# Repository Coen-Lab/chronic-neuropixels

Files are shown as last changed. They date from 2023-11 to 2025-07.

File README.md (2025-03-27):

# Apollo Implant Parts List and Instructions
For more information on the chronic implant detailed in this repository, please refer to our [eLife paper](https://elifesciences.org/articles/98522).  

## Issues and Discussions
* NOTE: On 14/06/2024 the files were updated to allow for larger inter-probe distances (a commonly requested feature). We believe this works well, but we have not tested the updated parts ourselves. Please contact us if you have any issues. This will change the behaviour of the parts slightly for Inter-Probe distances between 2 & 4 mm (in short, the height of the payload walls now increases, rather than the lid being extended). If you want to continue using the older files, please use an earlier version of the repository.
* If you have any problems with the implant, or difficulty sourcing the components etc. please use the "Issues" feature of github. 
* If you have ideas/feature requests or you want to ask a question, please use the "Discussions" feature of github. 
* If you have designed your own adaptations to the Apollo Implant that you think would be useful to the community, please submit a pull request to the repository, following the instructions shown [here](https://github.com/Coen-Lab/chronic-neuropixels/tree/main/XtraModifications).

## NOTE
Please be aware that all .ipt files were created useing Autodesk Inventor _2023_. To edit the files and save them in your preferred format, you will need to download this software [free for educational use](https://www.autodesk.com/education/edu-software/overview?sorting=featured&filters=individual). You will need the _2023_ version, or later, to open/edit the files.
 <br>
 <br>

The [commercially available NP2.0](https://www.neuropixels.org/order) probes have a different form-factor from the previous release (NP2_Alpha). We have an implant for the new version, and the design is posted here. However, it has undergone less testing, so please let us know if you have any issues with these parts, or if you use them successfully! Most of the images below reference the NP2_Alpha build, although the same documentation applies to both versions and we plan to update this in the future. There are two versions of the commercially available NP2.0 probes: those with a "metal cap" (also called a dovetail) and those without. The Apollo Implant will be tested with probes that do _not_ have the metal cap, to minimise the size and weight of chronic implants. However, with the adjustable parameters, it should be possible to accomodate probes with metal caps as well.

## Parts List
In this repository are all the parts required to build the chronic implant (not including glue, dental cement, etc.).
Files are adjustable using annotated parameter tables. Please watch “SupplementaryVideo_1.mp4” ([found here](https://www.biorxiv.org/content/10.1101/2023.08.03.551752v3.supplementary-material)) if you are unfamiliar with this process. You will also need Autodesk Inventor which is free for educational use. This allows you to, for example, change the angle of the docking module, spacing between probes, or thickness of the walls. However, be aware that parameters like “length of exposed probes” are estimates based on our own use and not exact. The default values are those we use in the lab for a typical insertion, although we change them as needed. 

Files are also inter-linked, such that changes you make to the parameters of Payload will cause changes in Docking, and DockingHolder. Usually, these are changes you want because it means all the parts will fit together. However, you should be aware that these are happening, and can be overridden if needed.

Files specific to versions 1 and 2 of Neuropixels are in NP1 and NP2 folders. Other parts are in the base folder and can be used (in some cases with a parameter change) for either version. NOTE: The "PayloadHolder" was updated on 27/09/2023 to add a minor adjustment for NP1 sizing. The "PayloadCap" was updated on 13/10/2023 for a minor adustment to better-accommodate NP1 probe thickness.

- [Payload module](https://github.com/Coen-Lab/chronic-neuropixels/tree/main#np1_payload-or-np2-alpha_payload)
- [Payload module holder](https://github.com/Coen-Lab/chronic-neuropixels/tree/main#np1_payloadholder-or-np2-alpha_payloadholder)
- [Lid](https://github.com/Coen-Lab/chronic-neuropixels/tree/main#np1_payloadlid-or-np2-alpha_payloadlid)
- [Docking module](https://github.com/Coen-Lab/chronic-neuropixels/tree/main#np1_docking-or-np2-alpha_docking)
- [Docking module holder](https://github.com/Coen-Lab/chronic-neuropixels/tree/main#np1_dockingholder-or-np2-alpha_dockingholder)
- [Constructor head](https://github.com/Coen-Lab/chronic-neuropixels/tree/main#universal_constructorhead)
- [Universal probe sharpener](https://github.com/Coen-Lab/chronic-neuropixels/tree/main#universal_probesharpener)

&nbsp;
### “NP1_Payload” or “NP2-Alpha_Payload”
This is the module that holds the probe(s). You will need one of these for each probe (or pair of probes) you use, and it is re-used across implantations. Print in Natural Rigid Resin 4000, including 4x M1 threaded inserts.

<p align="center">


</p>

&nbsp;
### “NP1_PayloadHolder” or “NP2-Alpha_PayloadHolder”
This is a holder that can be attached to the Payload Module for construction, painting, implants, storage, carrying around etc. There are two versions which can be produced from the save file by adjusting the binary “REDUCEDHOLDERVERSION” parameter.
*If REDUCEDHOLDERVERSION is "0", you will see the version used for payload construction (below, left). You only need one of these. Print in PA12, including 2x M3 insert.
*If REDUCEDHOLDERVERSION is "1", you will see the reduced version used general manipulation, storage, insertion etc. You need as many of these as would be useful. Print in PA12, including 2x M3 insert.

<p align="center">


</p>

&nbsp;
### “NP1_PayloadLid” or “NP2-Alpha_PayloadLid”
This is the lid for Payload Module, to be attached with glue after the probe is cemented in position. You will need one per probe. Print in PA12.  

<p align="center">


</p>

&nbsp;
### “NP1_Docking” or “NP2-Alpha_Docking”
This is the module that is cemented to the skull after being screwed to the Payload Module. A new Docking Module is required for each insertion. Print in Natural Rigid Resin 4000.  

<p align="center">


</p>

&nbsp;
### “NP1_DockingHolder” or “NP2-Alpha_DockingHolder”
This holds the Docking Module in place when using the constructor to combine the two modules. You only need one of these. Print in Natural Rigid Resin 4000, including 4x M3 insert.  
    
<p align="center">


</p>

&nbsp;
### “Universal_ConstructorHead”
This forms one end of the constructor setup (used to “safely” combine the docking and payload modules). You will only need one of these. Print in Natural Rigid Resin 4000.  
<p align="center">

</p>

&nbsp;
### “Universal_ProbeSharpener” 
This is a simple part that we use to hold the probe itself in order to sharpen them prior to construction. Note that it uses a screw to hold the probe: do not tighten it too much, or the probe base will break. 

&nbsp;
### Additional screws and bolts:
NOTE: Links are for reference but could be sourced elsewhere. The brass inserts can be easily inserted using a soldering iron and mild pressure. We typically do this in-house, but your 3D-printing company may also do this for you upon request.
* [M1 Brass knurled inserts](https://www.ebay.co.uk/itm/124738465135): To be heat-inserted into the Payload. Also available in large quantities on aliexpress from [many vendors](https://www.aliexpress.com/w/wholesale-m1-brass-inserts.html?spm=a2g0o.productlist.search.0).
* [M3 Brass knurled inserts](https://uk.rs-online.com/web/p/threaded-inserts/2040620): To be heat-inserted into the PayloadHolder and DockingHolder.
* [M1 Screws](https://www.accu.co.uk/cheese-head-screws/6425-SFE-M1-2-A2): To lock modules together (4 per module).
* [M3 5mm screws](https://www.accu.co.uk/flanged-button-screws/8592-SSBF-M3-5-A2): For connecting Payload Module holder to Thor Labs posts (3 total)
* [M3 10mm screws](https://www.accu.co.uk/flanged-button-screws/8595-SSBF-M3-10-A2): For connecting Constructor Head to Thor Labs posts (3 total) and also for securing the Docking Module in its holder (2-4 depending on your preference)
* [M3 20mm screws](https://www.accu.co.uk/flanged-button-screws/8600-SSBF-M3-20-A2): For tightening the payload module holder (one per payload module holder)
* [Thor labs posts](https://www.thorlabs.com/thorproduct.cfm?partnumber=MS3R/M): At least 3 for the constructor, more to hold the probes etc.

&nbsp;
&nbsp;
## Assembly 
NOTE: Links are for reference but could be sourced elsewhere. The brass inserts can be easily inserted using a soldering iron and mild pressure. We typically do this in-house, but your 3D-printing company may also do this for you upon request. 
This section describes how to put all the parts together. We recommend practicing on dummy probes (or even on probes that are already broken!) to get used to it, since specific steps can be finicky.   
### MATERIAL: 
* Blu Tack 
* Epoxy glue (e.g., Araldite ARA-400007) 
* Super glue 
* Silver wire and soldering  

&nbsp;
### 1. CHECKING THE PARTS: 
1.  Before fixing the probe, perform full assembly procedure without the probe to ensure the parts fit together. 

&nbsp;
### 2. FIXING A PROBE TO THE PAYLOAD MODULE 
1.  Using Blu Tack, position payload module and coat it with a thin layer of epoxy (so that the probe will stick to it). 
2.  Carefully bring the probe (usually holding the flex with two fingers and pushing the probe down with the index finger) onto the payload module. Make sure you push it to the end of the payload module. If you are aiming for a deeper implant than the parameters allow (>6.5 mm) you could push the probe beyond the end of the payload module. Check for probe alignment, and readjust the angle manually. Add more epoxy to fix the probe to the module – you can cover the base and parts of the electronics, but it’s usually good to avoid covering the GND and REF electrodes since they can be used to check for good soldering (or to solder GND and REF here directly). While applying epoxy, you can keep the probe in position using the tip of forceps. 
3.  Short the GND and the REF by soldering a silver wire in between (this can also be done beforehand). This step and the overall grounding are currently being discussed and improved (see troubleshooting). 
4.  Fold the flex and insert it in the slot on the inside of the lid. Then push the lid down and glue it by putting super glue on both sides of contact with the payload module. If you’ve soldered a silver wire for your ground, make sure it sticks out. You can then fold the flex and slide the connectors end in the slot on the outside of the lid. 
5.  You can now use the payload holder to sharpen your probe. 

<p align="center">

<p align="center">
Stage 2.3 (left) and 2.4 (right) 
</p>  
 
&nbsp;
### 3. FIXING A SECOND PROBE TO THE PAYLOAD MODULE 
These steps are only if you want a second probe. If you don’t, you can close the empty side with a lid and make sure you close all gaps with epoxy or kwikcast. If you do, please follow these steps:
1. You must first sharpen the second probe. To do so, you can use the temporary probe holder (we have been using “ProbeSharpener.stl” to hold the probe during this process, but this hasn’t been heavily optimized). 
2. Then, you can assemble the second probe by repeating the same steps as before, while being extra careful not to touch the probe that is already attached to the docking module.  
 
&nbsp;
### 4. ASSEMBLING THE PAYLOAD AND THE DOCKING MODULES 
1. Position the docking module in the docking module holder. 
2. Position the payload module (with the probes) in the payload module holder. This step is easier if the payload module holder is at that stage independent of the docking module holder. The probe is secured in the holder, and then the holder is screwed in. Check the alignment of the probe.  
3. Slide the docking module holder until the docking module is fully covering the payload module and that the holes are aligned to the threads. While sliding, check for the good alignment of the probe. Screw in (we found using forceps to hold the screws was easier).  
4.	Unscrew the docking module from the docking module holder. You can now slide it away from the probe.   
5.	Unscrew the now fully assembled implant from the payload module holder.   
 
<p align="center">

<p align="center">
Stage 4.2 (left) and 4.5 (right)  
</p>  

&nbsp;
&nbsp;

This work is licensed under a
[Creative Commons Attribution-NonCommercial-ShareAlike 4.0 International License][cc-by-nc-sa].

[][cc-by-nc-sa]

[cc-by-nc-sa]: http://creativecommons.org/licenses/by-nc-sa/4.0/
[cc-by-nc-sa-image]: https://licensebuttons.net/l/by-nc-sa/4.0/88x31.png
[cc-by-nc-sa-shield]: https://img.shields.io/badge/License-CC%20BY--NC--SA%204.0-lightgrey.svg

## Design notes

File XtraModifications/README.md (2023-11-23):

# Community-driven additional parts
<p align="justify"> In this folder, you will find parts generated by members of the Neuropixels community. The folder indicates the primary use of the part. Some of these will not be published, and may no longer be in active use. Please contact the designer listed if you have any questions. </p>

## Have a part to upload?
If you have a part to upload, please _submit a pull request_. In the interests of the community, please include the following in your commit: 
1. <p align="justify"> Add files to the folder that matches your use-case: Animal_State (e.g. Mouse_Headfixed or Rat_FreelyMoving). If the folder doesn't exist, you can create it (e.g. Platypus_FreelySwimming... I can hope). </p>
2. <p align="justify"> Add _one_ file per part and name the file according to ProbeType_Function (e.g. NP1_HeadstageHolder). </p>
3. <p align="justify"> Add parts in an editable format where possible _IF_ the software used is freely accessable to those in educational institutions. This will allow other members of the community to adjust the parts to their needs. Otherwise, upload a standard CAD format (e.g. STP or STL). </p>
4. Edit the README to include:
   * Sub-heading with the same name as your file.
   * A description of the part and how you use it.
   * One or two (but no more) images of the part.
   * The material that you typically use to print the part.
   * Your contact details.

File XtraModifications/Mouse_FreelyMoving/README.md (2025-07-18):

# Parts principally used with freely-moving mice
Each part will have a file associated with it, and where possible, this will be in an editable format. It will also include the material typically used to print the part, and the contact details of the designer. Please acknowledge the designer appropriately if you use any of these parts.  

- [NP1_HeadstageHolder](https://github.com/Coen-Lab/chronic-neuropixels/tree/main/XtraModifications/Mouse_FreelyMoving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)
- [NP1_HeadstageHolder_top & NP2-Alpha_HeadstageHolder_top](https://github.com/Coen-Lab/chronic-neuropixels/tree/main/XtraModifications/Mouse_FreelyMoving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)
- [NP2_SingleProbeMiniatureDockingWithHeadstageHolder & NP2_SingleProbeMiniaturePayload](https://github.com/Coen-Lab/chronic-neuropixels/tree/main/XtraModifications/Mouse_FreelyMoving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)
- [NP1_Payload_SingleProbe_Hollow & NP1_HeadstageHolder_DockingMount](#NP1_Payload_SingleProbe_Hollow-&-NP1_HeadstageHolder_DockingMount)
- [NP2_SingleProbeDockingWithHeadstage_ANGLED](#NP2_SingleProbeDockingWithHeadstage_ANGLED)

## NP1_HeadstageHolder
### Function
The NP1_HeadstageHolder was designed to allow free-moving recordings with the [Neuropixels 1.0 version](https://github.com/Coen-Lab/chronic-neuropixels/tree/main/NP1) of the Apollo implant and probes. It prevents damage to the ZIF pads during recordings. In our first recordings with the NP1 implant, we folded the probe flex underneath the caps (within the implant) so that the ZIF connector of the probe permanently protruded from the top of the implant (Fig 1A). During recordings, the headstage was connected to the probe and sat unsupported above the implant/animal.
<br>
<br>
Whilst recordings were possible in this configuration, the force exerted by the animal movement on the ZIF connector introduced noise into the recordings. This force and tension on the ZIF connector later damaged the gold pads on the flex, result in frequent error #14, 'BIST_ERROR', for the Parallel Serial Bus probe tests, which indicates a poorly seated probe. 
<br>
<br>
The headstage can be attached to the NP1_HeadstageHolder with epoxy (permanent) or a wrap of parafilm (temporary). Prior to recordings, the arms of the NP1_HeadstageHolder are slid onto the ridges of the NP1_Payload (as with the NP1_PayloadHolder) (Fig 1B). The probe flex is lopped between the NP1_Payload and NP1_HeadstageHolder and attached to the ZIF connector at the base (Fig 1C). Importantly, for this to work the flex needs to be full length. 

<p align="center">
  
</p>

### Material
Selective laser sintering. Material: Nylon PA12. Printed by: www.sgd3d.co.uk. Weight (without the headstage) = 0.5 g 

### Contact
Design was by Nathanael O'Neill, a postdoc in the Lignani lab, UCL email: skgtnon@ucl.ac.uk 
Freely moving recordings using NP1_HeadstageHolder were performed by Nathanael O'Neill and James Street 
The dimensions of the headstage mount of the NP1_HeadstageHolder were from [Emily A. Aery Jones](https://github.com/emilyasterjones)'s excellent [protocol](https://github.com/emilyasterjones/chronic_NPX_mouse) 

### Sofware used
Autodesk, Fusion360 2.0.17721 x86_64

## NP1_HeadstageHolder_top & NP2-Alpha_HeadstageHolder_top
### Function
This part was designed to facilitate freely-moving recordings using a single Neuropixels 1.0/2.0-Alpha probe. Its design is based on the Payload Holder, which was modified to fit the headstage and enable its connections.

*Advantages*
- Stability of probe-headstage connection increases SNR
- Easier and quicker to perform a recording (as the recording cable connection is easier to perform in an awake animal than the flex cable / ZIF connection)

*Disadvantages*
- Increased implant weight and height as mouse carries the headstage permanently

*How to use*
1. Protect the headstage electronics by applying some epoxy resin on it. Be mindful of the flex cable / ZIF connector. Wait at least 30 min for it to dry before applying epoxy on the other side of the headstage.
2. After printing the holder, verify that the headstage fits tightly inside it: it shouldn't move inside the holder, but also shouldn't be so tight that a great amount of force is needed to slide it in place. If necessary, file the inside of the holder to make room for the headstage.
3. Verify that the holder can be properly attached to the payload module. It should 'stick' to the payload module solely by friction. If necessary, after implantation you may add tape, dental cement, or other material to guarantee it will be secure in place, however keep in mind that you will need to do the reverse process during the explantation surgery!
4. (during surgery, after cementing and grounding the probe) Remove the implant from the Payload Holder and connect the headstage to the probe and slide it into the Headstage Holder as you mount the holder in the implant. Pay attention to the orientation of both the headstage (recording cable connection must align with the hole on the top of the holder) and the Holder (it must align with the grooves of the payload module, where it will slide in place). Slide it as much down as possible. In the end, verify that the connections are well-done by recording from the probe.
5. Cover the hole for the recording cable using a small piece of tape that can be removed for recordings, and glued back at the end of them. This will prevent dirt (*eg* cage bedding) from entering into the component.
6. Think about housing! A taller homecage is preferable, as is placing the food pellets in the floor of the cage and using a longer sipper tube for the water. Don't place small igloos or 'tunnels' in the cage.

In our hands, lighter mice (close to 20g in BW) take around 1 week to recover from the implantation surgery, while heaver mice (around 30g) take only a couple of days. We have attached the headstage and holder to the implant at the end of the implantation surgery, however you may perform this step on a separate surgery.

<p align="center">
  
</p>

### Material
Stereolithography (SLA) printing in a Form 2. Material: Resin Rigid 4000. Printed in-house. Weight (without the headstage) = 1.4 g (NP1.0) or 1.1g (NP2.0-Alpha)

### Contact
Design by Filipe Mendes (Champalimaud Research Hardware and Software Platform), Joana Catarino and José Teixeira (Systems Neuroscience / Mainen Lab). Freely-moving recordings using this component were performed by Joana Catarino and José Teixeira.
<br>

Filipe Mendes - filipe.mendes@research.fchampalimaud.org
<br>
Joana Catarino - joana.catarino@ki.se
<br>
José Teixeira - jose.gomesteixeira@donders.ru.nl

### Sofware used
Solidworks Professional SP5 2022

## NP2_SingleProbeDockingWithHeadstage_FullyParameterised & NP2_SingleProbeMiniaturePayload

### Function

This part was designed to have a minimal footprint, for a single Neuropixels 2.0 probe with a headstage that can be 
attached on the implant for long periods of time (e.g. in free moving experiments or in the homecage between 
experiments). The available .stp docking part leaves 3.5mm of probe exposed and has a contact angle of 16 degrees. A 
fully parameterised version is also included, which allows the user to set angles, tapers and amount of probe exposed.
This parameterised file was generated with Autodesk 2024 and is not backwards compatible.

Asset 4



## NP2-Alpha_SingleProbeDockingWithHeadstage & NP2-Alpha_SingleProbePayload

### Function

This part was designed to have a minimal footprint, for a single Neuropixels 2 Alpha probe with a headstage that can be 
attached on the implant for long periods of time (e.g. in free moving experiments or in the homecage between 
experiments). The available .stp docking part leaves 3.5mm of probe exposed and has a contact angle of 16 degrees.




### Material
Printed at SWC-FabLab with a Form 3. Material: Resin Rigid 4000.

### Contact
Design was by Simon Townsend (SWC FabLab, Sainsbury Wellcome Centre, UCL) with Stephen Lenzi (Margrie Lab).
<br>
Stephen Lenzi - s.lenzi@ucl.ac.uk
<br>
Simon Townsend - simon.townsend@ucl.ac.uk

### Sofware used
Autodesk Inventor 2023

##  NP1_Payload_SingleProbe_Hollow & NP1_HeadstageHolder_DockingMount ##

### Function

This design has a modified payload module for a single Neuropixels 1.0 probe achieving reduction in weight, and a headstage-holder that can be mounted to sides of any default NP1 docking module, achieving reduction in height. The trough-holes on the NP1 headstage are used to attach the headstage to the headstage holder (the holes on the holder require same threaded insert nuts as in the payoad module).

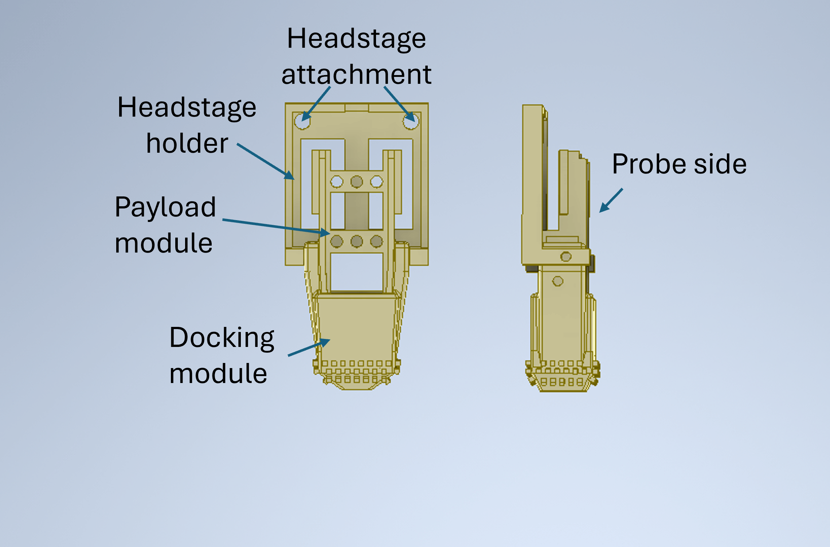
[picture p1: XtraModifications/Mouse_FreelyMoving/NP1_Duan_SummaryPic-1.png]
Asset 5


### Material
Printed at SWC-FabLab with a Form 3. Material: Resin Rigid 4000.

### Contact
Design by Ivana Orsolic (Duan Lab, Sainsbury Wellcome Centre, UCL) and Simon Townsend (SWC FabLab, Sainsbury Wellcome Centre, UCL).
<br>
Ivana Orsolic - i.orsolic@ucl.ac.uk
<br>
Simon Townsend - simon.townsend@ucl.ac.uk

### Sofware used
Autodesk Inventor 2023 & 2024

## NP2_SingleProbeDockingWithHeadstage_FullyParameterised_Fin & NP2_Mounting_bigger

### Function

This part is a modified version of the `NP2_SingleProbeDockingWithHeadstage_FullyParameterised`. It includes an added fin to improve stability and facilitate the assembly of the docking and payload components for Neuropixels 2 probes.
We have included files for a larger constructor specifically designed for Neuropixels 2.0 probes (single side). This bigger constructor makes it easier to handle and assemble the Payload and Docking Modules for NP2, simplifying the assembly process and improving ease of use.

**Advantages:**

- **Improved Stability:** The added fin provides additional support during insertion, reducing the risk of misalignment or damage to the probe.
- **Easier Assembly:** The enlarged rail guide system simplifies the process of assembling the docking and payload, making it more user-friendly.
- **Update to version v2** The recent version 17/07/25 (V2) has a reinforced handlebar and a pin that is compatible with the ADAL1 Ø1.25 mm Ceramic Mating Sleeve (a standard ceramic fiber optic mating sleeve, e.g. [Thorlabs ADAF1](https://www.thorlabs.com/thorproduct.cfm?partnumber=ADAF1)). This ceramic sleeve is installed with epoxy glue on the headstage circuit; even with a single point of contact, the circuit stays in place.

**Usage in Our Lab:**

We have successfully used this modified part to enhance stability and ease of assembly in our Neuropixels 2.0 experiments with freely-moving mice.

### Images
<table>
  <tr>
    <td>
      NP2 Single Probe Docking With Headstage
    </td>
    <td>
      NP2_SingleProbeDockingWithHeadstage_FullyParameterised_fin v2
    </td>
  </tr>
</table>

NP2_newmounting_assembled

### Material (docker)

- **Printing Method:** Stereolithography (SLA)
- **Material Used:** Resin Rigid 4000
- **Printed By:** In-house using a Formlabs Form 3 printer
- **Weight:** Approximately 1.2 grams

### Contact

Design by Fabio Ricci (Iurilli Lab,Istituto Italiano di tecnologia)

- **Email:** fabio.ricci@iit.it
- **Website** https://iurillilab.github.io/

### Software Used

Autodesk Inventor 2024

## NP2_SingleProbeDockingWithHeadstage_ANGLED

### Function
1) modded the docking part to hide the flex-wire and hold the headstage in an angled surface. perforated to reduce weight.
2) added viewing ports (different files for front / side / back ports) to view the shanks during implantation.

**Advantages:**

- **neatly tucks the flex-wire aand headstage way from reach of the mouse, while keeping a low profile of the implant - removes the need for a headstage holder piece

### Images
461432149-75324f65-eeb7-42da-b118-8c76df258c56
461433459-d0ebba90-00d5-4965-93bd-71425331d72e
461433880-5ac68c36-57cd-4f48-995c-30d8f6bc821c
461432268-7c579789-b243-47f7-a64b-3ee4ec9dda72

### Material

- **Printing Method:** Stereolithography (SLA)
- **Material Used:** Surgical Guide Resin  - a biocompatible Photopolymer Resin, 50 micron layer line resolutions on Formlabs SLA printers, Form 2 and Form 3B.
 can be disinfected with 70% Isopropyl Alcohol for 5 minutes , or autoclaved. 
- **Printed By:** In-house workshop using a Formlabs Form 3 printer
- **Weight:** Approximately 1.2 grams, (0.4 grams with transperent resin used in prototyping, but non autoclavable)

### Contact
Design by Shahaf Weiss (Max-Planck institute for brain-research, Frankfurt am Main, Germany)
- **Email:** shahaf.weiss@brain.mpg.de

### Software Used

Autodesk Inventor Professional 2025

---
<br>
<br>

[][cc-by-nc-sa]

This work is licensed under a
[Creative Commons Attribution-NonCommercial-ShareAlike 4.0 International License][cc-by-nc-sa].

[][cc-by-nc-sa]

[cc-by-nc-sa]: http://creativecommons.org/licenses/by-nc-sa/4.0/
[cc-by-nc-sa-image]: https://licensebuttons.net/l/by-nc-sa/4.0/88x31.png
[cc-by-nc-sa-shield]: https://img.shields.io/badge/License-CC%20BY--NC--SA%204.0-lightgrey.svg

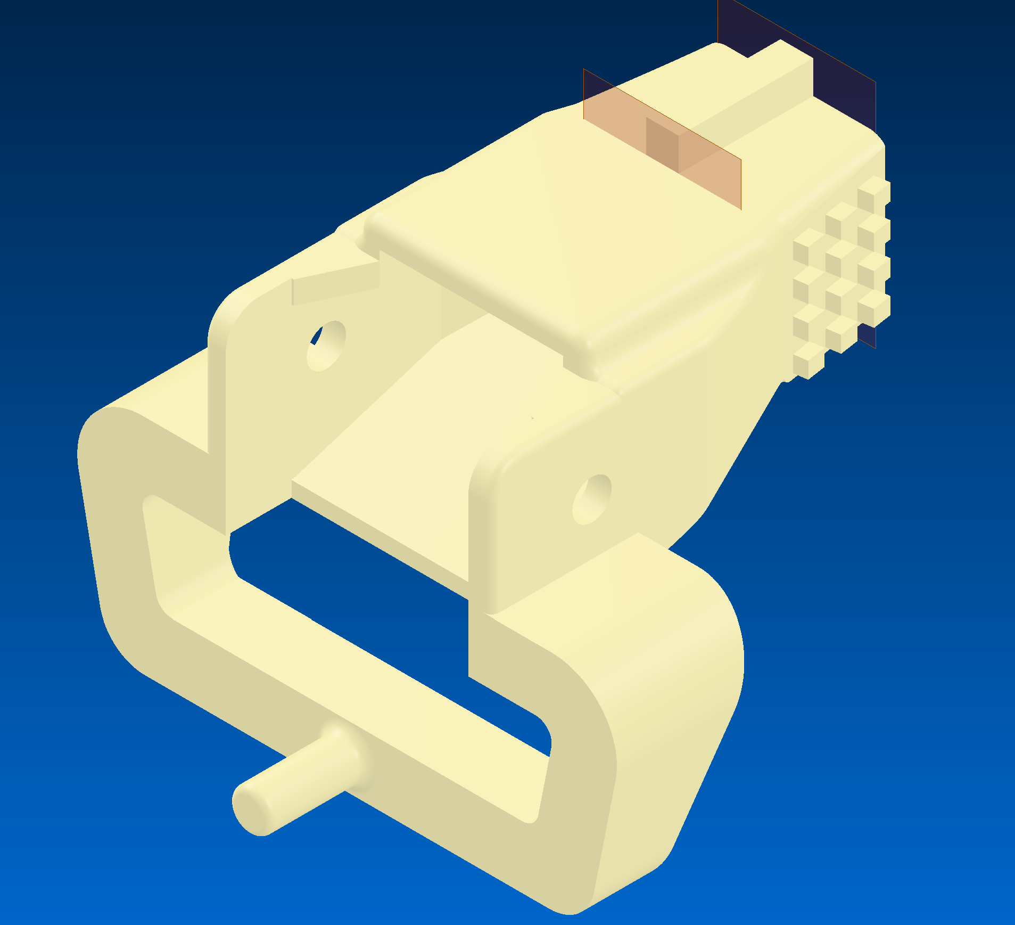
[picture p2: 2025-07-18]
XtraModifications/Mouse_FreelyMoving/NP2_Mounting_bigger/NP2_SingleProbeDockingWithHeadstage_FullyParameterised_fin v2.png

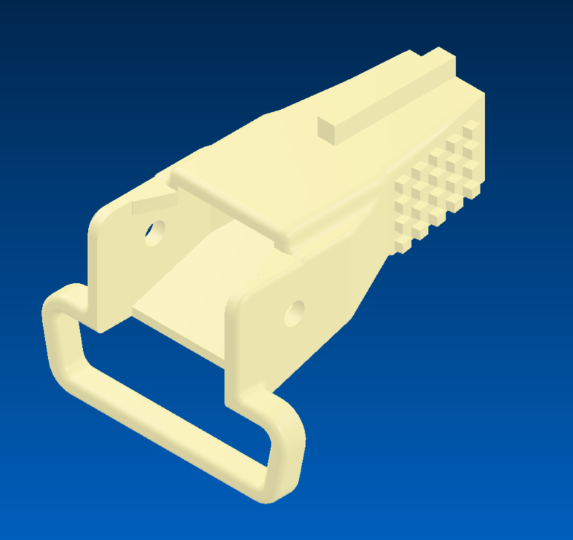
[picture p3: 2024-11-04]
XtraModifications/Mouse_FreelyMoving/NP2_Mounting_bigger/NP2_SingleProbeDockingWithHeadstage_FullyParameterised_fin.png

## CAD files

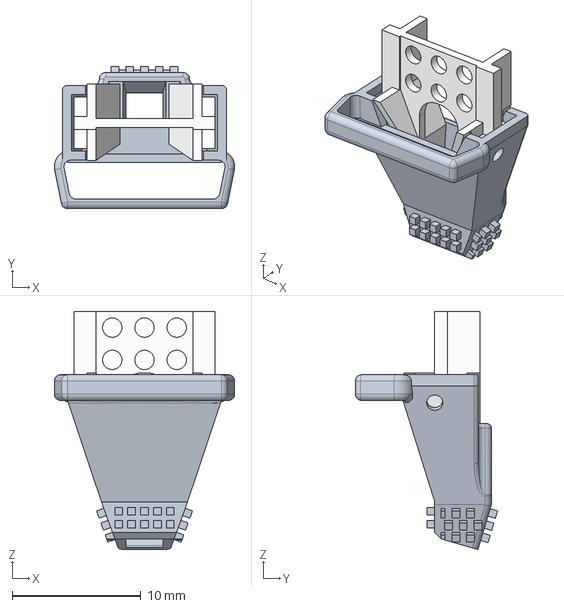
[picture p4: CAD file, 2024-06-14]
XtraModifications/Mouse_FreelyMoving/NP2-Alpha_SingleProbePayload.stp
14.0 x 11.0 x 18.4 mm

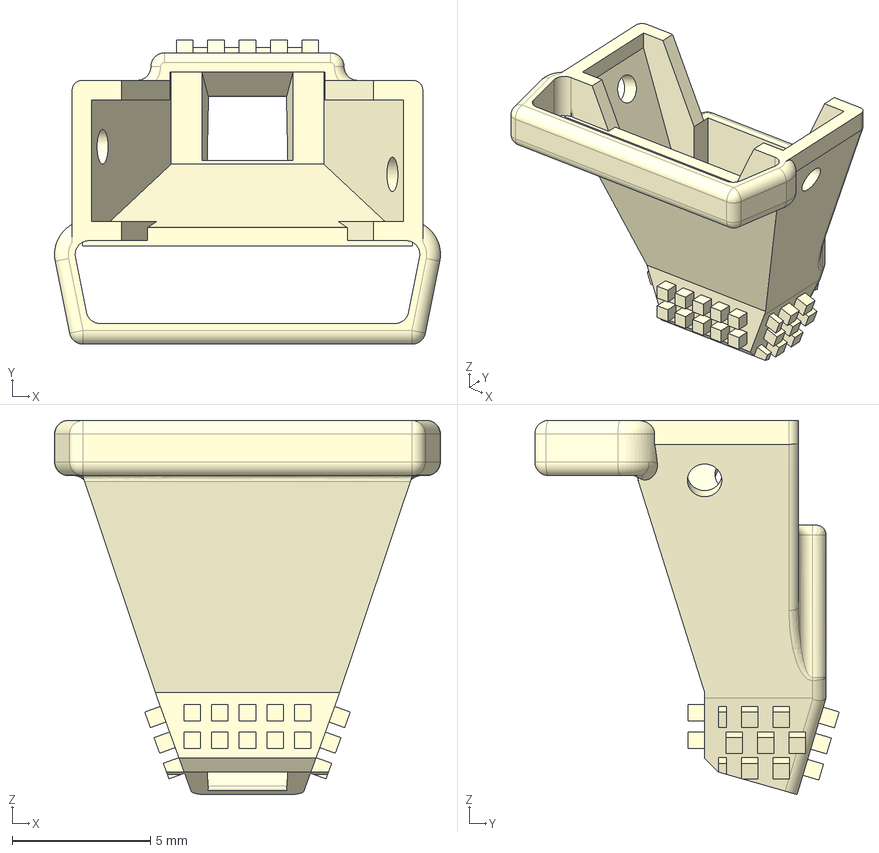
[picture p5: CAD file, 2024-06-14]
XtraModifications/Mouse_FreelyMoving/NP2-Alpha_SingleProbeDockingWithHeadstage.stp
14.0 x 11.0 x 13.6 mm

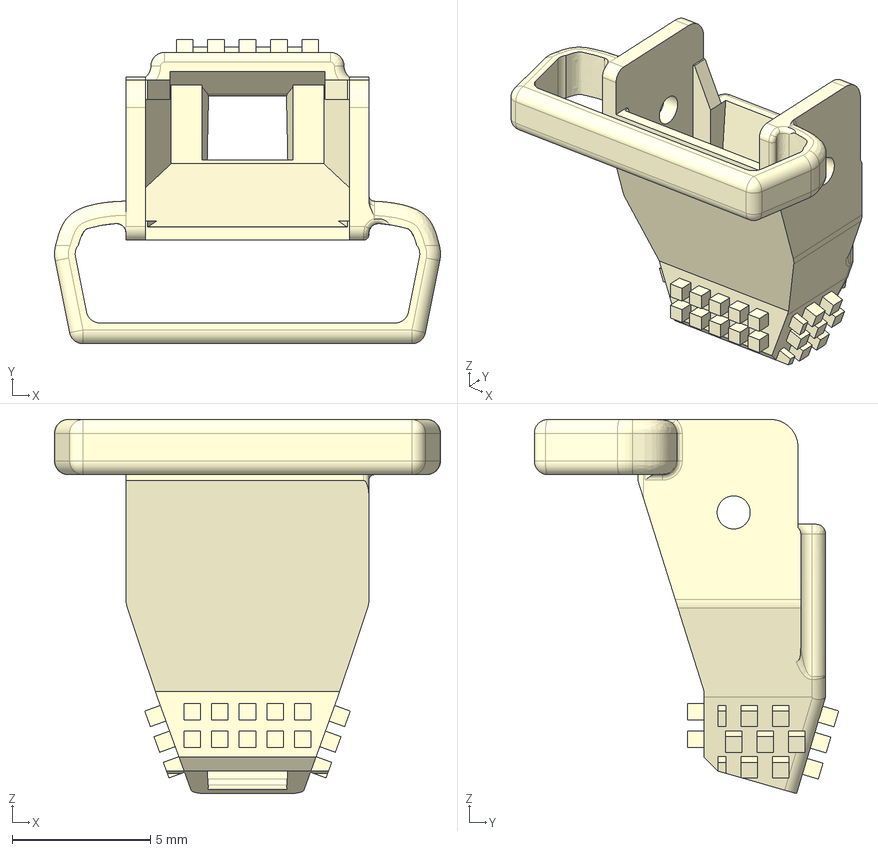
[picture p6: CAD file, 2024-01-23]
XtraModifications/Mouse_FreelyMoving/NP2_SingleProbeMiniatureDockingWithHeadstageHolder.stp
14.0 x 11.0 x 13.6 mm

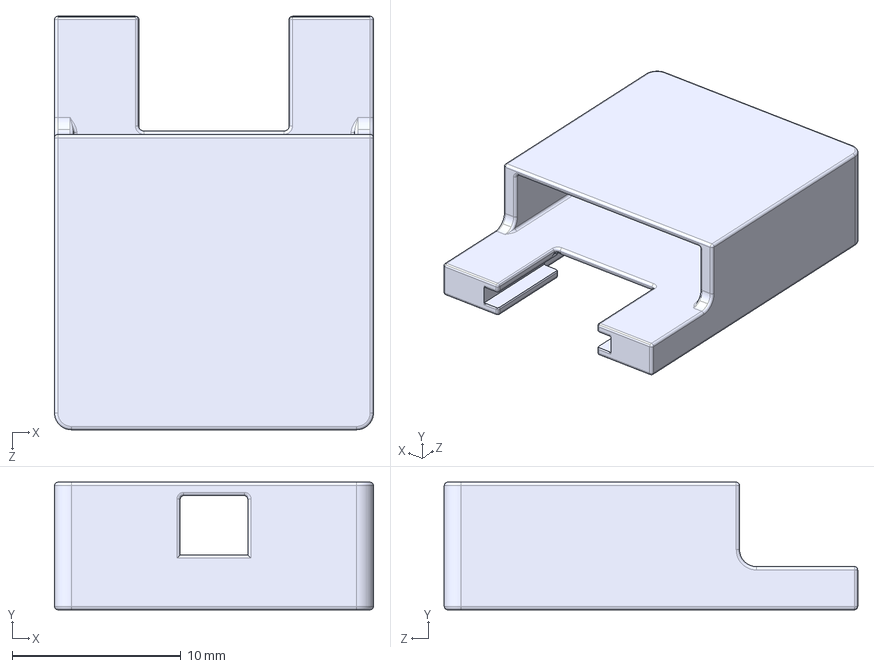
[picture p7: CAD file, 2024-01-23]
XtraModifications/Mouse_FreelyMoving/NP1_HeadstageHolder_top.STEP
18.9 x 7.56 x 24.5 mm

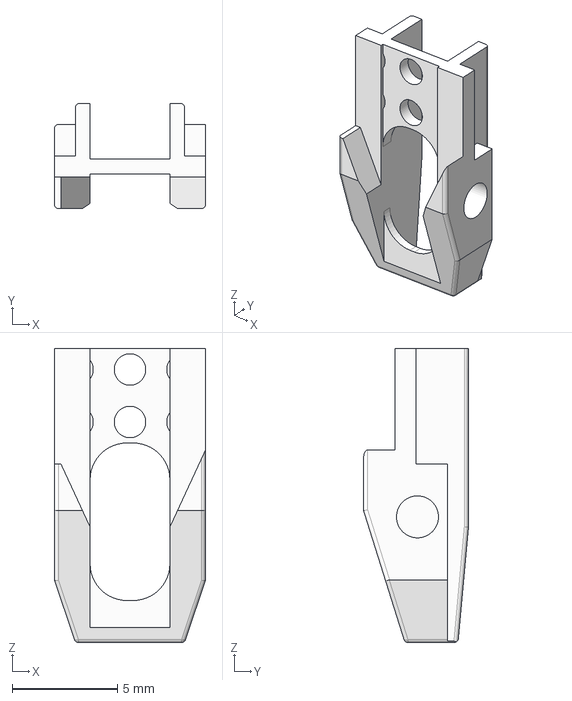
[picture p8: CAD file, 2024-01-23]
XtraModifications/Mouse_FreelyMoving/NP2_SingleProbeMiniaturePayload.stp
7.20 x 5.00 x 14.0 mm

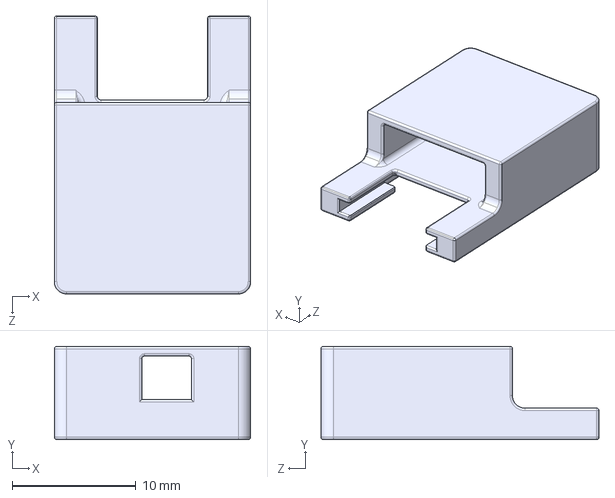
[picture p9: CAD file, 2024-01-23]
XtraModifications/Mouse_FreelyMoving/NP2_HeadstageHolder_top.STEP
15.9 x 7.56 x 22.5 mm

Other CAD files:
NP1/NP1_Docking.ipt
NP1/NP1_DockingHolder.ipt
NP1/NP1_Payload.ipt
NP1/NP1_PayloadHolder.ipt
NP1/NP1_PayloadLid.ipt
NP2-Alpha/NP2-Alpha_Docking.ipt
NP2-Alpha/NP2-Alpha_DockingHolder.ipt
NP2-Alpha/NP2-Alpha_Payload.ipt
NP2-Alpha/NP2-Alpha_PayloadHolder.ipt
NP2-Alpha/NP2-Alpha_PayloadLid.ipt
NP2/NP2_Docking.ipt
NP2/NP2_DockingHolder.ipt
NP2/NP2_Payload.ipt
NP2/NP2_PayloadHolder.ipt
NP2/NP2_PayloadLid.ipt
Universal/Universal_ConstructorHead.ipt
Universal/Universal_ProbeSharpener.ipt
XtraModifications/Mouse_FreelyMoving/NP1_HeadstageHolder_DockingMount.ipt
XtraModifications/Mouse_FreelyMoving/NP1_HeadstageHolder_Slim.f3d
XtraModifications/Mouse_FreelyMoving/NP1_Payload_SingleProbe_Hollow.ipt
XtraModifications/Mouse_FreelyMoving/NP2_Mounting_bigger/NP2_SingleProbeDockingWithHeadstage_FullyParameterised_fin v2.ipt
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

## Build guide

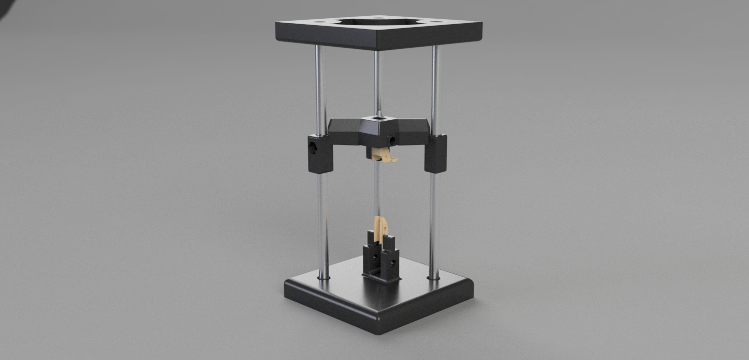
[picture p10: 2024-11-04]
XtraModifications/Mouse_FreelyMoving/NP2_Mounting_bigger/NP2_mounting_bigger/NP2_newmounting_assembled.png

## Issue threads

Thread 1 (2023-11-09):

What is  heat-inserted "

Virginia9733, 2023-11-09:
Sorry for the naive question, but what's the details of "heat-inserted"?
[M1 Brass knurled inserts]: To be heat-inserted into the Payload.

What's the recommended temperature, and what's the procedure?

Many thanks!

pipcoen, 2023-11-09:
No worries! Typically, we use a standard soldering iron and "press" the threaded insert into the hole with the tip of the soldering iron. For temperature, it depends on the material you are using for the print, but a good rule of thumb is to start at a lower temp and increase it. I think* I usually use ~300C.

Closed 2023-11-09.

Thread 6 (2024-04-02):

How to assemble the NP2_SingleProbeMiniature?

Virginia9733, 2024-04-02:
Thank you for sharing this wonderful design.

However, I am a bit confused about how to assemble the NP2_SingleProbeMiniature.
Following the instruction, the probe should be attached to the probe side, but it's too narrow for the probe and almost all the shank will be hidden inside the payload and docking.
On the contrary, looks like the head stage side fits the NP2 so well, however, there is no space in the docking for the shanks.

Is it possible to have more clear pictures of the step-by-step ensemble process? Also, it would be great to show how the flex cable is folded when connecting to the headstage.

Not only for the miniature design, it would be great to have more pictures of how to place the headstage and flex cable using NP1_HeadstageHolder_top & NP2-Alpha_HeadstageHolder_top design.
Thank you so much!

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

pipcoen, 2024-04-02:
@stephenlenzi are you able to help out with this?

stephenlenzi, 2024-04-02:
That is indeed correct the part shown here is for the most recent commercial 2.0 probes. We do also have a design that fits the NP2-Alpha. I'll add it to the repo either by the end of this week or early next.

Virginia9733, 2024-04-03:
Thank you so much for all the comments!
My other question is, can we possibly have more pictures about how to attach the head stage to those designs, as well as how to place and connect the flex cable based on the design of NP2_SingleProbeMiniature and NP2-Alpha_HeadstageHolder_top design? This part is also a bit vague to me.

Thank you very much!

pipcoen, 2024-04-03:
@stephenlenzi thanks! maybe you can upload a couple of extra photos when you are adding the NP2-Alpha version

stephenlenzi, 2024-04-03:
Yes - a good idea I'll do that

Virginia9733, 2024-04-03:
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

Sorry for bombarding messages.
I just tried the implantation using the NPX2 Alpga dummy probe, I have no clue how should I connect the head stage, where should I place it, how should I connect the flex cable, etc., especially if I have two probes.

Many thanks!

pipcoen, 2024-04-03:
I believe this is the headstage holder from @gomesteixeira? If so, you need to put the headstage in such that the connection point is lined up with the square hole at the top. As written in the instructions, you should be able to check that this fits tightly etc. I believe it only supports attaching a single probe.

gomesteixeira, 2024-04-04:
Hi all.
@pipcoen is correct that this design only supports a single probe!
Regarding the question you asked, we fold the flex cable into the empty (probe-less) side of the payload module, as much as possible. Only the wider part at the end of the flex cable, where you connect to the headstage, should remain out of the implant. See the pictures attached for reference.
We always test the probe+headstage before implanting, but during the surgery you can only connect the headstage (and mount the headstage holder) after cementing the implant. Make sure you place the holder in the same side as the headstage so you're not straining the flex cable connection.
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

Virginia9733, 2024-04-17:
Thank you very much! Much clearer now! Looking forward to the updated NP2-Alpha version of the SingleProbeMiniature.

pipcoen, 2024-04-22:
Sorry for the delay @Virginia9733. Steve was very prompt, but I have been away for two weeks. This is now uploaded, and I'm closing this issue, but please re-open it if anything is still unclear.

Closed 2024-04-22.

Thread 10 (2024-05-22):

Using SmoothOn Body double as alternative to Kwik-cast?

SusanL82, 2024-05-22:
Hello,

Our local Czech WPI distributor does not sell Kwik-cast or Kwik-sil.
Do you think we can use SmoothOn Body Double as an alternative for filling the gap at the bottom of the docking module?
We've also considered using wax instead, but personally I worry about getting it on the probe and blocking all the contacts. Any ideas?

Thanks,
Susan

cbimbo, 2024-05-22:
Hi Susan,

I would say that any soft-enough, biocompatible silicon should work. Hard to predict though, and I've never used SmoothOn Body Double. Maybe try with a dummy probe (or a glass pipette, or anything thin)? Otherwise some people put vaseline (heating it up a bit so that it's more fluid and easier to apply).
Also, we don't always put Kwik-sil at the bottom of the docking module (just duragel, then the shank are "in the air"). That could be an option?

Best,
Célian

pipcoen, 2024-06-17:
Closing this issue for now, but can re-open if needed.

Closed 2024-06-17.

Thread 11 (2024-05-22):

Problems with heat-inserting threaded inserts in docking module holder

SusanL82, 2024-05-22:
Hi everyone,

We've since found a workaround, but I'm posting here anyway in case it helps someone:

We've been having problems with heat-inserting threaded inserts in the docking holder for the NP1 probe. Basically the walls of the insert-hole kept cracking when we tried to insert the metal parts.

This was particularly a problem because we can currently not print resin parts in the lab, and our printing service is quite expensive.

Initially we used threaded inserts for M3 screws that had a 5mm outer diameter. These completely destroyed the plastic when inserted.
We then switched to the M2.5 threaded inserts from CNCkitchen, which have a 4.6mm outer diameter and are 4mm long. These inserts fit much better, but still cracked the plastic (see pictures). And you can see that there is very little melting around the metal parts.

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

So, wondering if everything I thought I knew about plastic was wrong, I then tried to melt one of our broken docking holders with a hot soldering iron. I could not. The hole-walls remained solid for a long time and at the point where the plastic became somewhat flexible it just lost structural integrity and cracked/tore in a similar way that happened with our inserts.
I think this is because resin is not a thermoplast (at least our printed resin does not act as a thermoplast). I was able to make a small scorch mark with a very hot soldering iron (approx 400C), but there was no melting.

We ended up just gluing/reinforcing the cracks in our best docking holder with some 5-minute epoxy and this seems to hold up fine for now.

Of note:
We were able to insert the larger inserts in the payload holder just fine.  Similarly, we're able to insert the tiny inserts in the payload module without too much trouble. I think the larger/wider amount of plastic around the holes keeps things from cracking.

Best,
Susan

SusanL82, 2024-05-22:
Actually, I think I can close this myself :)

pipcoen, 2024-05-24:
Hi @SusanL82,
This is surprising because we've never had this issue before (and neither have other labs as far as I know). Could you just confirm the material you printed these pieces in for future reference? Typically we use M3 threads with a 5.5mm outer diameter... I wonder if the company that printed your files (or perhaps an error in a file that was our fault?!) cause the holes to be printed too small,

Best,

Pip

SusanL82, 2024-05-26:
I also don't now anyone who has these problems before (I certainly never encountered them with PLA parts).
The holes in our prints had a diameter of a little under 4mm. We downloaded the STL files a while ago and ended up printing the parts in September last year.
The docking holder fits fine around the metal bars, so I guess only some holes came out small.

I checked and our printing company made the docking holder and payload holder out of PA12, which I believe is a type of nylon.
I remembered wrong earlier and we only made the smaller modules out of resin. I've edited my original post to reflect this.

I really don't know what happened (the not-melting part is very strange to me, but maybe nylon has a much higher melting point than other plastics?). I hope that somehow this is helpful for reference at least.

Closed 2024-05-22.

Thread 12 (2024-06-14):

Expanding probe base width part of NPX 2 design

atombysx, 2024-06-14:
Hi,
Thank you for the design. It's very useful!

I want to make the two probes 0.8mm offset to each other, e.g. the coordinates of the centre of the two probes would be AP -3.0, ML 2.0 and AP -5.0, ML 2.8.

So this is quite easy to achieve on the NP2_payload file by changing parameters d4 from 2.05mm to 2.45mm and d6 from 1.9mm to 2.3mm.

But for the NP2_Docking, I'm a bit lost and I'm not very familiar with working on Inventor. I see that the Docking file should change according to the Payload file and I probably need to change EndCone size to allow space for the shanks.

But it keeps returning erorr updating on AnglePlane1, AngleNub1-1, AngleNub1-2, SlicePlane2.

Is the way I approach this not gonna work?

pipcoen, 2024-06-14:
This is an interesting request, and I can see it being useful for others. Unfortunately, with FENS coming up, I'm unlikely to be able to look into implementing it for now... To clarify, are you trying to just "widen" the payload to give you the room to adjust the probes relative to each other (should be pretty easy) or do you want to actually offset the walls of the payload relative to each other (trickier)

atombysx, 2024-06-14:
> This is an interesting request, and I can see it being useful for others. Unfortunately, with FENS coming up, I'm unlikely to be able to look into implementing it for now... To clarify, are you trying to just "widen" the payload to give you the room to adjust the probes relative to each other (should be pretty easy) or do you want to actually offset the walls of the payload relative to each other (trickier)

I would say the first one. Currently I just want some room to adjust the probe relative to each other. But the docking also needs to be expanded for the extra room, right?

pipcoen, 2024-06-17:
Hmmm. Can you try with the most recent version of the files? I just made the same changes as you (d4 from 2.05mm to 2.45mm and d6 from 1.9mm to 2.3mm). I didn't receive any errors and the NP2_Docking updated appropriately.

If you still get the error, can you share the user parameters you are using?

FYI, I did get an issue updating the "lid" part--but let's solve this contradiction first :)

atombysx, 2024-06-17:
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

Hi, thanks for checking!

I just tried to replicate the same errors from the new github files:

Yes, the docking can change according to changes of d4 and d6 in NP2_payload file.

Before, I didnt know how to make NP2_docking change accordingly without changing parameters in the parameter list. So I changed User Parameters as well.

However, even though changing d4 and d6 works, changing user parameters can still lead to errors like this:
   NP2_Docking.ipt: Errors occurred during update
     AnglePlane1: Could not build this Plane by Offset from Plane
       Missing or invalid face/plane for offset work plane.  Use Redefine Feature to change the work plane definition.
     Sk:AngleNub1: Could not build this Sketch
       Could not find the plane for defining the sketch coordinate system.  Use Redefine Sketch to select a new face.
       Dimension to reference geometry that could not be resolved.  Use Edit Sketch to delete the reference geometry and rebuild the dimension.
     Ex:AngleNub1-1: Could not build this Extrusion
     SlicePlane2: Could not build this Plane by Line and Angle to Plane
       Zero or multiple solutions for Plane by Line and Angle to Plane.  Use Redefine Feature to change its definition.
         Missing or undefined inputs for Plane by Line and Angle to Plane.  Use Redefine Feature to change its definition.
           Could not attach to edge: edge could not be found.
     Ex:Slice2: Could not build this Extrusion

In my design, I want to change exposed probe length to 4.5 and SliceAngle2 to 10 degrees, but this error keeps happening.

pipcoen, 2024-06-17:
Hmmmm, I have no problem doing these changes. Here is what I did:

1. Change the params d4 and d6
2. Update the docking file
3. Change the probe exposure to 4.5mm and the angle to 10 degrees.

I didn't get any errors... If this doesn't work for you, can you confirm the version of inventor you are using, and send the exact files you are using here. (To "make" a file update, you need to click the little lightning bolt--you can see the video for an example of this).

atombysx, 2024-06-17:
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

Hi, thanks for reminding about the inventor version! I just installed 2023 version and now it worked (it was 2024 before). Sorry for the extra steps of troubleshooting. I will print some prototypes first and will let you know how well it goes.

pipcoen, 2024-06-17:
Ah, glad that worked! Yes, the versioning with Inventor isn't great :( Closing this issue for now, but please do post your updates in the discussion, and if it works, it would be great to upload modified files to share with the community!

Closed 2024-06-17.

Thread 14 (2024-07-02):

How does the NP2_PayloadLid (commercial) attach?

tofof, 2024-07-02:
In the preprint, figure 6 A/F show how the 2.0alpha payload lid attaches to the assembly of the payload and docking modules. The 2.0 commercial's lid is a different design, and it's unclear exactly how it's intended to fit.

Are any of the following correct? None seems completely correct.

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

 If not, is the lid itself the correct dimensions relative to the default 2.0 commercial parts?

tofof, 2024-07-02:
After adding the GapBetweenModules to the constraint I put on inserting the probe holder into the docking module at the nose, the second arrangement gets better but still doesn't look quite right.

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

pipcoen, 2024-07-03:
Hiya. Thanks for bringing this up.

Just fyi, there are pictures of the commercial assembly in the newly released [eLife preprint](https://elifesciences.org/reviewed-preprints/98522), Fig 1B. Your second image is correct. The reason it appears that there is a gap at the back is because there is a little "room to breathe" between the docking module and the payload. If you were to add a constraint that aligns the holes together of the two modules, you would see the gap is much-reduced (see image below). There is a small gap remaining to account for any issues with printing etc.

My advice would be to print the parts and assemble the first module without any probes to make sure everything fits together nicely. If there are any issues, please let me know! Closing this now, but feel free to re-open if my answer isn't clear.

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

Closed 2024-07-03.

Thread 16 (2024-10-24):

single NP2 probe docking holder

ChangQing-SH, 2024-10-24:
Hi  there,

There is a docking holder for a single NP2 probe, and the NP2 docking holder (for 2 probes) is too large for this purpose.

While the current holder might work, I’m concerned that if it doesn't align properly, it could damage the probe.

Best,
Jon

cbimbo, 2024-10-24:
Hi,

Thanks for flagging this. We haven't yet made a holder compatible with the 1-probe docking. In the meantime we recommend you use blu tack to fill in the gap between the docking and the holder. By sliding the docking slowly enough into the payload to make sure things align properly it should be ok!

Célian

pipcoen, 2024-10-24:
@stephenlenzi Perhaps you could comment on this as the primary user of this version of the implant?

stephenlenzi, 2024-10-24:
The approach I used to assemble was:

1) Assemble the docking part and a payload (without a probe in it) in the assembly apparatus.
2) Have the dock loose, and the payload fixed firmly.
3) While the dock and empty payload are together, adjust the screws that hold the docking piece until it is well aligned. Make sure the pieces slot together well.
4) Swap out the payload without a probe for one with a probe, and carefully bring the parts together, making sure by eye not to bump into anything.

I haven't designed any extra pieces for this assembly as the need did not arise for me. I think it does require a bit more caution and making sure by eye not to come into contact with the shanks, but I have done many this way without breaking any probes.

pipcoen, 2024-10-24:
Thanks Steve! I am going to mark this as closed @ChangQing-SH as we don't plant to develop new pieces specifically for this use case, but if you design one personally please upload it! Although it sounds like Steve's solution may be fine already.

riccifab, 2024-11-02:
Hi @pipcoen @ChangQing-SH  @stephenlenzi  My pull request solve this issue, let me know, we printed it and tested it went pretty smooth, maybe I have to recheck tolerances on the new docker.

Closed 2024-10-24.

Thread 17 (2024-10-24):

Increased Inter-Probe Distance on Apollo Implant Causes Docking Holder Model Failures

Maxwell-X-Chen, 2024-10-24:
I set the interprobe distance to 6.5 mm and applied it to all components, but the model crashes when it gets to the docking holder.

`Error Log:
   NP2_DockingHolder.ipt: Errors occurred during update
     Ex:Side2: Problems occurred while building this Extrusion
       The feature as specified did not change the number of faces (and may not have affected the part).  Accept the feature that resulted, or use Edit Sketch or Edit Feature to change the feature definition.
     Fillet:PostHolder1: Could not build this Fillet
       The attempted Fillet operation is too complicated for selected inputs. Try changing the edges, applying the fillet(s) separately or in a different order, else try a face fillet or a different radius.
     Mirror1: Could not build this Mirror
       Execute failure while making this pattern.
         Execute failure while making this pattern.
     Mirror2: Could not build this Mirror
       Execute failure while making this pattern.
         Execute failure while making this pattern.
     Ex:ThreadHole: Problems occurred while building this Extrusion
       The feature as specified did not change the number of faces (and may not have affected the part).  Accept the feature that resulted, or use Edit Sketch or Edit Feature to change the feature definition.
     Chamfer:ThreadInsert: Could not build this Chamfer
       The specified Chamfer distance is too large for selected inputs. Try with a smaller distance.
     Pat:ThreadInsert: Problems occurred while building this Circular Pattern
       One of the features involved in the pattern has associated problems.
         One of the features involved in the pattern has associated problems.`
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

pipcoen, 2024-10-24:
Thanks for raising this @Maxwell-X-Chen! There was an errant parameter that was causing issues at inter-probe distances above 4mm for the holder. I've now fixed this and pushed the change. It seems to work fine, so I'm closing the issue, but let me know if it doesn't!

Closed 2024-10-24.

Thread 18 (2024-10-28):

Cover for NP2_SingleProbeMiniatureDockingWithHeadstageHolder?

jonahpearl, 2024-10-28:
Hi there — thank you for these great designs and a nice protocol. I'm wondering if there is a headstage cover that goes along with the NP2_SingleProbeMiniatureDockingWithHeadstageHolder? In the photos it appears not, I'm wondering if anyone has perhaps made one or has recommendations for how to go about designing one. My goal is to implant a single Npx 2.0 probe with the smallest footprint possible + protect the headstage.

(Also, in the README, it seems like this piece is labeled as "NP2-Alpha_SingleProbeDockingWithHeadstage_FullyParameterised", so I was a bit confused when trying to sort out which piece was which, but AFAICT this piece will work with the commercial 2.0 headstages).

Thanks!

cbimbo, 2024-10-31:
Hi,

In this version the headstage isn't covered, it's just attached to the implant with the handle. You can cover it with epoxy to protect it. I haven't heard of anyone making one! The design would largely depend on your needs, so it's a bit hard to help -- but there are other headstage holders on the GitHub, maybe you could get some inspiration from those?

The NP2-Alpha isn't the commercial version, so you should indeed look at [NP2_SingleProbeDockingWithHeadstage_FullyParameterised.ipt](https://github.com/Coen-Lab/chronic-neuropixels/blob/main/XtraModifications/Mouse_FreelyMoving/NP2_SingleProbeDockingWithHeadstage_FullyParameterised.ipt). I've corrected the README which had the wrong title. Thanks!

Hope this helps,
Célian

pipcoen, 2024-11-04:
Closing this issue, but reopen @jonahpearl if you don't think it's resolved!

jonahpearl, 2024-11-04:
Thanks both. Celian, do you find that kwik-cast / kwik-sil is an ok epoxy for protecting it, or can you recommend another one? I've had issues in the past with kwik-cast seeping in between the pins of ZIF-style connectors.

jonahpearl, 2024-11-07:
Thanks Célian. I don't totally understand — in this setup, the headstage is attached to the piece that is cemented to the skull. So presumably if you epoxied the headstage to that piece, it would only be able to be used once..? What am I missing here?

cbimbo, 2024-11-07:
Sorry I was just talking about the protection, not the attachment. I think @stephenlenzi used Kwik-Cast to secure the HS to the docking module, but I may be wrong?

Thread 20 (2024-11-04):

Increasing exposed probe length after increasing the interprobe distance on Apollo Implant causes build errors

Maxwell-X-Chen, 2024-11-04:
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
After increasing the interprobe distance I then tried to change the exposed probe length from the default 5mm to 3.8mm however it throws me this error
```
NP2_Docking. ipt: Errors occurred during update
AnglePlane1: Could not build this Plane by Offset from Plane
Missing or invalid face/plane for offset work plane. Use Redefine Feature to change the work plane definition.
Sk: AngleNub1: Could not build this Sketch
Could not find the plane for defining the sketch coordinate system.
Use Redefine Sketch to select a new face.
Dimension to reference geometry that could not be resolved.
Use Edit Sketch to delete the reference geometry and rebuild the dimension.
SlicePlane2: Could not build this Plane by Line and Angle to Plane Zero or multiple solutions for Plane by Line and Angle to Plane.
Use Redefine Feature to change its definition.
Missing or undefined inputs for Plane by Line and Angle to Plane. Use Redefine Feature to change its definition.
Could not attach to edge: edge could not be found.
```

pipcoen, 2024-11-04:
Hi Maxwell... Can you confirm all the params you are using, and that you definitely have the latest files? I don't get any error when doing this?

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

Maxwell-X-Chen, 2024-11-04:
Hi Pip, I redownloaded the latest file, and tried to do this again and still get the same error
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

Maxwell-X-Chen, 2024-11-04:
Hi Pip, I redownloaded the latest file, and tried to do this again and still get the same error...
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

Maxwell-X-Chen, 2024-11-04:
> Hmmm. I am using the same params without issue... which version of Autodesk are you using?

Autodesk Inventor Professional 2025

Maxwell-X-Chen, 2024-11-04:
I was able to get around this error by swapping the order or operation somehow. So I increased the exposed probe distance first and then increased the inter probe distance. Thanks for all the help still!

pipcoen, 2024-11-04:
Ah, okay. For me, the order didn't matter. If you do have a chance to check it on 2023, that would b great to know, just so I can update the info on the main readme.

Maxwell-X-Chen, 2024-11-04:
Yup, i will update here once i get the 2023 version.
Also i noticed that after the parameter changes. The square things on the side of the docking module all disappeared. is it supposed to happen?
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

pipcoen, 2024-11-04:
No, as you can see, they are still there on my version... I'm guessing this is a inventor-version issue... in which case, probably beyond the scope of Coen-support ;)

However, if it doesn't work smoothly with 2023 (I didn't get any errors or warnings at all) please do let me know and we'll get to the bottom of it. Re-opening for now.

Maxwell-X-Chen, 2024-11-04:
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
Same error in Autodesk Inventor 2023. Retried again with files freshly downloaded from git

pipcoen, 2024-11-05:
We tracked this down to subtle a versioning issue. Should  be solved now. Please reopen if not!

Closed 2024-11-05.

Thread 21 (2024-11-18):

request90 degree HS holder

WeissShahaf, 2024-11-18:
Dear Devs,

is it possible to have a version of the "NP2_SingleProbeDockingWithHeadstage_FullyParameterised.ipt" with a 90 rotated headstage-holding ring? for case where we want to implant the probes  rotated AP, but not have the headstage sticking out side ways?

riccifab, 2024-11-24:
Hi, you mean something like this ?
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

riccifab, 2024-11-24:
[Custom_weissShahaf.zip](https://github.com/user-attachments/files/17893555/Custom_weissShahaf.zip)
Uploaded here the rotated heastage ring, i will probably have no time to check, both the inventor file and the step file are here, print it and let me know, the ring is parametrized in rotation (last parameter) so you can rotate it how you want

WeissShahaf, 2024-11-24:
thank for the quick reply.
but no i meant 90 degrees in the horizontal plane. so that if we implant a NP 2.0 with the shanks arranged anterior -posterior, the headstage would stick out AP and not to the left or right,

riccifab, 2024-11-24:
No problem, Ok now i get it, seems a quick fix, if rotated it will be lower in height no ? Describe it better how you picture this even with paper its fine

WeissShahaf, 2024-11-24:
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

riccifab, 2024-11-25:
I was hoping for something better, what are the point of connection here, should i increase the surface ? i think the ring has to connect in something stable enough so i was thinking to put it lower.
It's probably a good idea and a quick fix but placing the ring there is gonna be not as stable as we wish

WeissShahaf, 2024-11-25:
BTW,
we're using a modification of the original design, with increased surface area for the headstage (found it a bit wobbly). which is only 0.1g heavier due to a "cheese holes pattern".
now with the tilted ring, it also protects the wire nicely:

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

WeissShahaf, 2025-07-02:
I've made a pull request

riccifab, 2025-07-02:
This is very nice, what are you using to insert the payload to this docker ? I'm a little concerned about using the screws to block the docker while aligning because of the weakened  structure due to the windows. I cannot see the images too, also i think you should update the readme in the main folder but either way works.
We kind of solved this problem by adding a pin on the handlebar like this (sorry i only have this photo)

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

The circuit has a socket that fits that pin that you can buy from thorlabs and glue it to the circuit with some epoxy, its very stable and doesnt rotate

We are still testing it but your way seems less bulkier, kudos

WeissShahaf, 2025-07-02:
payload to docking- we do by hand. and use bigger screws (metric)
we made a holder that is similar to the original, but, has 2 screws, that when tightened push against each other to release the docking module

pipcoen, 2025-07-18:
Closing @cbimbo. Thanks!

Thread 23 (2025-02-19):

Problem with inter-probe distance of NP2.0 payload module

Huang-Yu-Chen, 2025-02-19:
Hello!

Recently, I planned an NP2.0 dual implant with an inter-probe distance of 1.963 mm.
After printing the payload module and attaching the probes, I measured the actual inter-probe distance and it was 2.81 mm, a lot bigger that planned.

First, I suspect that our 3D printer has an error. In the payload module CAD file, the thickness of the wall between the 2 probes is 0.663 mm. The actual printed distance is 0.71 mm, which I think isn't a huge error (By the way, we are wondering if this scale of printing error is a common problem)

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

Then I inspected the function of the thickness of that wall (in the CAD sketch), it is 2 * ( InterProbeDist / 2 - 0.65 mm).
Indeed, 2 * ( 1.963 / 2 - 0.65 ) is 0.663.

But here's the problem:
I think the subtraction of 0.65 is assuming that the distance between the shanks and bottom of the probe base (as shown is the attached figure, labeled as d) is 0.65 mm.
I checked the technical brochure of NP2.0 four shanks with silicon spacer, the thickness of probe base (as shown is the attached figure, labeled as t)  is 1.28 mm.
That means, the function is assuming that the shanks are positioned at about the middle of the probe base ("d" is about half a "t").
But in the actual probe, the shanks are actually positioned more closer to the top of the probe base than to the bottom.

I couldn't find the in length of "d" in the official documents, so I made a measurement (not accurately), and it was around 0.8 to 0.9 mm.

If the function is modified, then the actual inter-probe distance will be closer to the planned.

Thanks in advance!

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

pipcoen, 2025-02-24:
@Huang-Yu-Chen thank you for this invaluable feedback. The designs here were produced before we had access to these probes ourselves, and so we did no have this measurement (d, and t in your diagram).

Just so I can be sure of the "orientation" before I update the dimensions as you suggest, you are saying it should be:

2 * ( InterProbeDist / 2 - 0.85 mm)?

I am not sure how this varies across probes... I hope to make the measurements myself soon and corroborate your measurements. Thanks again for this invaluable contribution!

Huang-Yu-Chen, 2025-02-25:
Thanks for your awesome implant design! It's fun using it :)

Yes, it should be around
2 * ( InterProbeDist / 2 - 0.85 mm)
if my measurement is accurate, which I'm not really confident about.

I emailed Neuropixels support team regarding the length of "d", but haven't received a response yet.

I'll inform you if I got a reply.

pipcoen, 2025-02-27:
Thank you! This has now been updated (Along with a warning that low inter-probe distances may cause printing issues). I have closed this issue, but please add any updates to the discussion section!

Closed 2025-02-27.

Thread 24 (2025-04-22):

Folding the flex onto NP2.0 payload module

Huang-Yu-Chen, 2025-04-22:
Hi!

I'm doing an NP2.0 4-shank dual implant, and since the NP2_PayloadLid doesn't have a slot underneath like the NP1_PayloadLid and NP2-Alpha_PayloadLid do, I assume the flex should be folded directly onto the payload module, with the lid closed on top—like in the figure below.

This makes me a bit worried that this might damage the flex, since the Neuropixels User Manual stated: "Do not pinch the flex of the probe and maintain a minimum bending radius of 3 mm."

Could this potentially be an issue?

Thanks in advance!

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

Closed 2025-07-02.

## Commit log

2023-08-04 Initial upload of CAD files
    [ConstructorHead_v1.0.ipt, DockingHolder_NP1_v1.0.ipt, DockingHolder_NP2_v1.0.ipt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]
2023-09-27 New parameter for PayloadHolder
    Updated "PayloadHolder" to add the ability to adjust the distance between the arms (helps for NP1 where it was a little too tight)
    [PayloadHolder_v1.0.ipt]
2023-10-13 Update for file refs and NP1
    Updated file references--some of the cross-part dimension references were buggy. Also added a "lip" by default to the NP1 lids to account for the larger thickness of these probes
    [DockingHolder_NP1_v1.0.ipt, DockingHolder_NP2_v1.0.ipt, Docking_NP1_v1.0.ipt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]
2023-11-06 Update of files
    Some default params, new naming convention, and minor improvements to parts
    [ConstructorHead.ipt, DockingHolder_NP1.ipt, DockingHolder_NP1_v1.0.ipt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]
2023-11-07 Update to naming convention for files
    Update to naming convention for files
    [DockingHolder_NP1.ipt, DockingHolder_NP2_Alpha.ipt, Docking_NP1.ipt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]
2023-11-07 Creation of Universal folder
    [Universal_ConstructorHead.ipt, Universal_ProbeSharpener.ipt]
2023-11-22 Added PRELIMINARY NP2 files
    [NP2_Docking.ipt, NP2_DockingHolder.ipt, NP2_Payload.ipt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]
2023-11-23 Reorganized contribution from Lignani lab
    [NP1_HeadstageHolder_Slim.f3d]
2023-12-13 Updated file names
    [NP1_PayloadLid.ipt, NP2-Alpha_PayloadLid.ipt, NP2_PayloadLid.ipt]
2023-12-15 Added Mainen Lab designs (figure missing)
    [NP1_HeadstageHolder_top.STEP, NP2_HeadstageHolder_top.STEP]
2023-12-21 Update README.md
    New M1 insert link
2024-01-16 adds mini np2 implant Docking and Payload parts
    [NP2_SingleProbeMiniatureDockingWithHeadstageHolder.stp, NP2_SingleProbeMiniaturePayload.stp]
2024-01-23 Fixed bug in NP2_DockingHolder File
    [NP1_DockingHolder.ipt, NP1_PayloadHolder.ipt, NP2-Alpha_DockingHolder.ipt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]
2024-04-05 adds parameterised np2.0 and updates readme
    [NP2-Alpha_SingleProbeDockingWithHeadstage_FullyParameterised.ipt]
2024-04-05 adds parameterised file and np2alpha designs
    [NP2-Alpha_SingleProbeDockingWithHeadstage.stp, NP2-Alpha_SingleProbePayload.stp, NP2_SingleProbeDockingWithHeadstage_FullyParameterised.ipt]
2024-04-12 Added files for Duan lab designs
    [NP1_HeadstageHolder_DockingMount.ipt, NP1_Payload_SingleProbe_Hollow.ipt]
2024-06-14 Change to allow for larger inter-probe distances
    This is a significant update to allow for larger inter-probe distances. As a result, there are some changes to how the parts interact (the previous "lip" that used to be generated by the lid no longer exists)
    [NP1_Docking.ipt, NP1_Payload.ipt, NP1_PayloadLid.ipt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]
2024-10-24 Update NP2_DockingHolder.ipt
    Fixed a parameter in the docking holder that prevented auto-adjustment at inter-probe distances > 4mm
    [NP2_DockingHolder.ipt]
2024-10-31 New mounting system
    Added a fin to the single probe docking part
    [Bars.ipt, Bigger_NP2_DockingHolder.ipt, NP2_DockingHolder.iam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]
2024-10-31 Assembled version ready
    [NP2_DockingHolder.iam, NP2_SingleProbeDockingWithHeadstage_FullyParameterised.ipt]
2024-10-31 Ready to pull request
    [Bars.ipt, ConstructorHead_bigger.ipt, NP2_DockingHolder_bigger.iam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]
2024-10-31 Ready for pull request 2
    [NP2_DockingHolder_bigger.iam, NP2_PayloadHolder_bigger.ipt]
2024-11-05 Update to solve version number issue with 2023 Inventor
    [NP2_Docking.ipt, NP2_Payload.ipt]
2025-01-29 Removed thickness difference in front section of support for NP2 and NP1 versions
    [NP1_Payload.ipt, NP2_Payload.ipt]
2025-02-27 Update NP2_Payload.ipt
    Updated the inter-probe distance calculation for NP2_Payload based on user feedback
    [NP2_Payload.ipt]
2025-07-02 viewing port
    [NP2_SingleProbeDockingWithHeadstage_ANGLED._frontipt.ipt, NP2_SingleProbeDockingWithHeadstage_ANGLED_backhole.ipt, NP2_SingleProbeDockingWithHeadstage_ANGLED_s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]
2025-07-02 renamed dir
    [NP2_SingleProbeDockingWithHeadstage_ANGLED._frontipt.ipt]
2025-07-17 Version 2 of singleprobeDockingWithHeadstage_FullyParametrised_v2
    [NP2_DockingHolder_bigger.iam, NP2_SingleProbeDockingWithHeadstage_FullyParameterised_fin v2.ipt]
2025-08-06 Delete XtraModifications/Mouse_FreelyMoving/NP2_SingleProbeDockingWithHeadstage_ANGLED/NP2_SingleProbeDockingWithHeadstage_ANGLED._frontipt.ipt
    empty file
    [NP2_SingleProbeDockingWithHeadstage_ANGLED._frontipt.ipt]
2025-08-06 Delete XtraModifications/Mouse_FreelyMoving/NP2_SingleProbeDockingWithHeadstage_ANGLED/NP2_SingleProbeDockingWithHeadstage_ANGLED_backhole.ipt
    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
    [NP2_SingleProbeDockingWithHeadstage_ANGLED_backhole.ipt]
2025-08-06 Delete XtraModifications/Mouse_FreelyMoving/NP2_SingleProbeDockingWithHeadstage_ANGLED/NP2_SingleProbeDockingWithHeadstage_ANGLED_sidehole.ipt
    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
    [NP2_SingleProbeDockingWithHeadstage_ANGLED_sidehole.ipt]
2025-08-06 Add files via upload
    added full files
    [NP2_SingleProbeDockingWithHeadstage_ANGLED._frontipt.ipt, NP2_SingleProbeDockingWithHeadstage_ANGLED_backhole.ipt, NP2_SingleProbeDockingWithHeadstage_ANGLED_s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]
2025-12-05 Update to fix minor resizing bug on NP2 implant
    [NP2_Docking.ipt, NP2_DockingHolder.ipt, NP2_Payload.ipt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]

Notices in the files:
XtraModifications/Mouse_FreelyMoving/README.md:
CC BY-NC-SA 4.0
